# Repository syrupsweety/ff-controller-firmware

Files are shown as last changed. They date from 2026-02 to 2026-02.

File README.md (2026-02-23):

# Force feedback manipulator firmware

This is a custom force feedback controller firmware for the RP2350 microcontroller with ROS2 integration.

## Hardware features

- Microcontroller: RP2350

- Input sensors:

  - Piezo sensor (12-bit ADC) for force/vibration detection
  - Analog joystick (X/Y axes, 12-bit ADC)
  - 3 digital buttons (active-low with pull-ups)

- Actuator interface: UART (9600 baud) for motor control

- Communication: I2C slave interface (400kHz Fast Mode, address 0x08)

## Software Architecture

- Firmware: Bare-metal C using Pico SDK

  - ADC reader with moving average filtering
  - I2C slave with IRQ-based TX/RX handling
  - UART motor command protocol (framed packets)

- ROS2 driver: C++ node running on host machine

  - Polls controller via I2C at configurable rate (default 50Hz)
  - Publishes sensor data to `/controller/input` topic
  - Subscribes to `/controller/motor_command` for actuator commands

## Protocol

- I2C Read: 8 bytes (controller data + XOR checksum)
- I2C Write: 4 bytes [START, speed, dir+enable, END]

## Build

- Firmware compiles to .uf2 for drag-and-drop flashing
- ROS2 packages build with colcon
- Automated build/flash scripts included

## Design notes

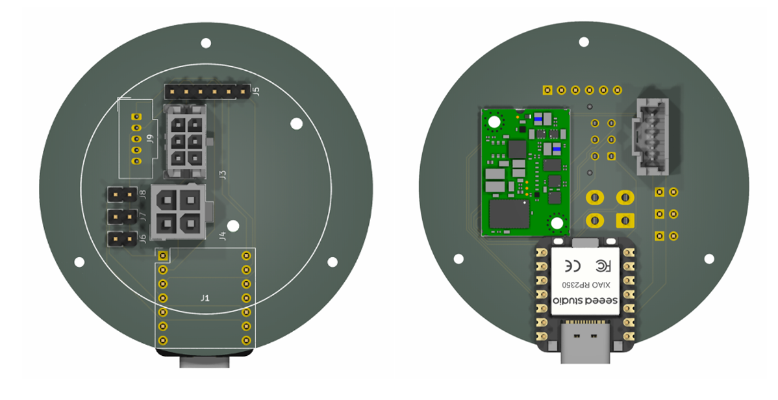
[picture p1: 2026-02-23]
schematics/screenshots/render.png

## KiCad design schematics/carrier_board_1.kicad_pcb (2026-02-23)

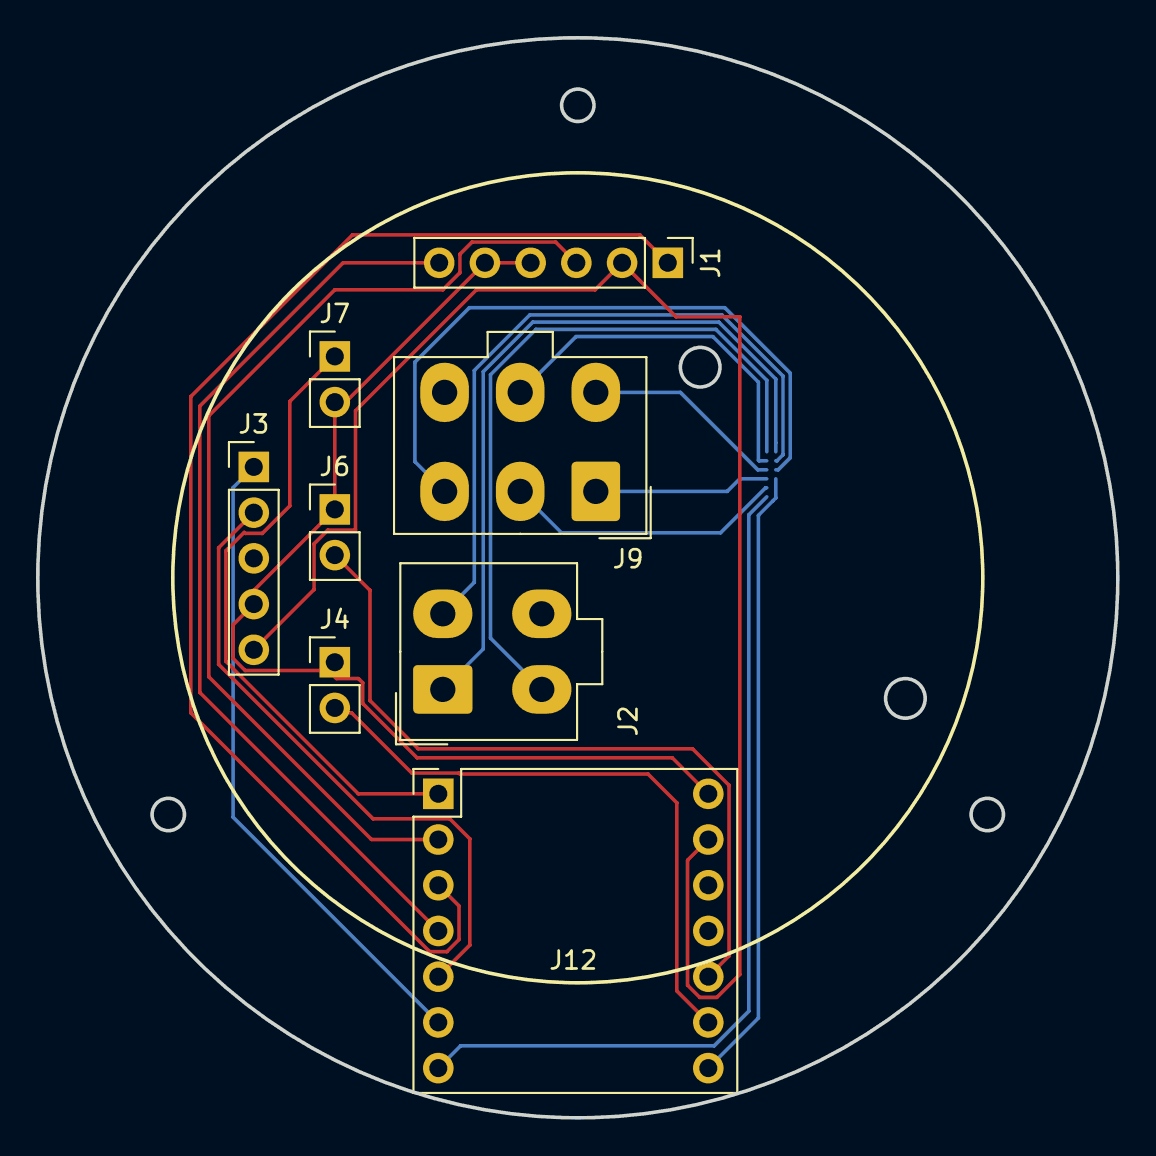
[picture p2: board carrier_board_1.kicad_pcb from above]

Board: 2 copper layers, 60.0 x 60.0 mm, 8 parts (0 on the bottom side), 10 nets.

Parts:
J1: joystick; PinHeader_1x06_P2.54mm_Vertical
J2: 4 pin BLDC; Molex_Mini-Fit_Jr_5566-04A_2x02_P4.20mm_Vertical
J3: econ; PinHeader_1x05_P2.54mm_Vertical
J4: button1; PinHeader_1x02_P2.54mm_Vertical
J6: button0; PinHeader_1x02_P2.54mm_Vertical
J7: piezo; PinHeader_1x02_P2.54mm_Vertical
J9: 6 pin BLDC; Molex_Mini-Fit_Jr_5566-06A_2x03_P4.20mm_Vertical
J12: XIAO RP2350; PinHeader_2x07_P2.54mm_Vertical

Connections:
unnamed: J1.LR (1), J12.A2 (5)
unnamed: J1.GND (2), J3.GND (4), J12.GND (4)
unnamed: J1.UD (3), J12.A1 (3)
unnamed: J1.B0 (5), J1.VCC (4), J3.5v (5), J4.1, J6.1, J7.2, J12.5V (2)
unnamed: J1.B1 (6), J12.D3 (7)
unnamed: J7.1, J12.A0 (1)
unnamed: J3.SDA (2), J12.SDA1 (9)
unnamed: J6.2, J12.D9 (10)
unnamed: J3.SCL (1), J12.SCL1 (11)
unnamed: J4.2, J12.D8 (12)

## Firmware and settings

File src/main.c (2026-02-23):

#include "pico/stdlib.h"
#include "hardware/adc.h"
#include "config.h"
#include "controller.h"
#include "i2c_slave.h"
#include "adc_reader.h"
#include "uart_motor.h"

int main(void) {
    // Standard Pico SDK initialization
    stdio_init_all();
    
    // Initialize hardware subsystems
    adc_init();
    adc_reader_init();
    controller_gpio_init();
    uart_motor_init();
    i2c_slave_init();
    
    printf("RP2350 Controller initialized @ 0x%02X\n", CONTROLLER_I2C_ADDRESS);
    
    controller_input_t input = {0};
    motor_command_t command = {0};
    
    while (true) {
        controller_read_inputs(&input);
        
        i2c_slave_prepare_response(&input);
        
        if (i2c_slave_get_command(&command)) {
            controller_process_command(&command);
        }
        
        sleep_us(1000);
    }
}

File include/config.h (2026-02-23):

#pragma once

#include "pico/stdlib.h"
#include "hardware/adc.h"
#include "hardware/i2c.h"
#include "hardware/uart.h"

// ===== I2C Configuration =====
#define CONTROLLER_I2C_PORT         i2c0
#define CONTROLLER_I2C_SDA_PIN      4
#define CONTROLLER_I2C_SCL_PIN      5
#define CONTROLLER_I2C_ADDRESS      0x08
#define CONTROLLER_I2C_BAUDRATE     400000  // 400 kHz Fast Mode

// ===== GPIO Pin Assignments =====
#define BTN_0_PIN                   9
#define BTN_1_PIN                   8
#define BTN_JOY_PIN                 3
#define PIEZO_ADC_PIN               0  // ADC0 -> GPIO26
#define JOY_X_ADC_PIN               2  // ADC2 -> GPIO28
#define JOY_Y_ADC_PIN               1  // ADC1 -> GPIO27

// ===== UART Motor Interface =====
#define MOTOR_UART_PORT             uart1
#define MOTOR_UART_TX_PIN           12
#define MOTOR_UART_RX_PIN           13
#define MOTOR_UART_BAUDRATE         9600
#define MOTOR_UART_ID               1

// ===== ADC Configuration =====
#define ADC_RESOLUTION_BITS         12
#define ADC_MAX_VALUE               ((1 << ADC_RESOLUTION_BITS) - 1)
#define ADC_SAMPLE_INTERVAL_US      1000

// ===== I2C Protocol Definition =====
#define I2C_RX_BUFFER_SIZE          16
#define I2C_TX_BUFFER_SIZE          16
#define PROTOCOL_START_BYTE         0xAA
#define PROTOCOL_END_BYTE           0x55
#define PROTOCOL_HEADER_SIZE        2
#define PROTOCOL_PAYLOAD_SIZE       3
#define PROTOCOL_FOOTER_SIZE        1
#define PROTOCOL_TOTAL_SIZE         (PROTOCOL_HEADER_SIZE + PROTOCOL_PAYLOAD_SIZE + PROTOCOL_FOOTER_SIZE)

// ===== Data Structures =====
typedef struct __attribute__((packed)) {
    uint8_t speed;      // 0-255
    uint8_t direction;  // 0=CCW, 1=CW
    uint8_t enable;     // 0=disable, 1=enable
} motor_command_t;

typedef struct __attribute__((packed)) {
    uint8_t buttons;            // Bitmask: bit0=BTN0, bit1=BTN1, bit2=JOY_BTN
    uint8_t reserved;           // Padding for alignment
    uint16_t piezo_value;       // 0-4095
    uint16_t joystick_x;        // 0-4095
    uint16_t joystick_y;        // 0-4095
    uint8_t checksum;           // Simple XOR checksum
} controller_input_t;

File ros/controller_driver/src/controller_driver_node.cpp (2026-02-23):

#include "rclcpp/rclcpp.hpp"
#include "controller_msgs/msg/controller_input.hpp"
#include "controller_msgs/msg/motor_command.hpp"
#include <linux/i2c-dev.h>
#include <sys/ioctl.h>
#include <fcntl.h>
#include <unistd.h>
#include <cstring>

class ControllerDriver : public rclcpp::Node {
public:
    ControllerDriver() 
    : Node("controller_driver"),
      i2c_fd_(-1),
      i2c_address_(0x08)
    {
        // Declare parameters
        this->declare_parameter<std::string>("i2c_device", "/dev/i2c-1");
        this->declare_parameter<int>("i2c_address", 0x08);
        this->declare_parameter<int>("publish_rate_hz", 50);
        
        // Initialize I2C
        init_i2c();
        
        // Create publishers/subscribers
        input_pub_ = this->create_publisher<controller_msgs::msg::ControllerInput>(
            "controller/input", 10);
        command_sub_ = this->create_subscription<controller_msgs::msg::MotorCommand>(
            "controller/motor_command", 10,
            [this](const controller_msgs::msg::MotorCommand::SharedPtr msg) {
                send_motor_command(msg);
            });
        
        // Timer for periodic input polling
        auto period = std::chrono::milliseconds(
            1000 / this->get_parameter("publish_rate_hz").as_int());
        timer_ = this->create_wall_timer(period, 
            std::bind(&ControllerDriver::poll_controller, this));
        
        RCLCPP_INFO(this->get_logger(), "Controller driver initialized");
    }

private:
    void init_i2c() {
        std::string device = this->get_parameter("i2c_device").as_string();
        i2c_address_ = static_cast<uint8_t>(
            this->get_parameter("i2c_address").as_int());
        
        i2c_fd_ = open(device.c_str(), O_RDWR);
        if (i2c_fd_ < 0) {
            RCLCPP_ERROR(this->get_logger(), "Failed to open I2C device: %s", device.c_str());
            return;
        }
        
        if (ioctl(i2c_fd_, I2C_SLAVE, i2c_address_) < 0) {
            RCLCPP_ERROR(this->get_logger(), "Failed to acquire I2C bus access");
            close(i2c_fd_);
            i2c_fd_ = -1;
            return;
        }
        
        RCLCPP_INFO(this->get_logger(), "I2C connected to 0x%02X on %s", 
                   i2c_address_, device.c_str());
    }
    
    void poll_controller() {
        if (i2c_fd_ < 0) return;
        
        controller_msgs::msg::ControllerInput msg;
        msg.stamp = this->now();
        
        // Request data from RP2350
        uint8_t buffer[8];
        if (read(i2c_fd_, buffer, sizeof(buffer)) == sizeof(buffer)) {
            // Validate checksum (XOR of first 7 bytes)
            uint8_t checksum = 0;
            for (int i = 0; i < 7; i++) checksum ^= buffer[i];
            
            if (checksum == buffer[7]) {
                msg.buttons = buffer[0];  // buttons is 1st byte
                msg.piezo_value = (buffer[2] << 8) | buffer[3];
                msg.joystick_x = (buffer[4] << 8) | buffer[5];
                msg.joystick_y = (buffer[6] << 8) | buffer[7];
                
                msg.joystick_x_norm = (static_cast<float>(msg.joystick_x) / 4095.0f) * 2.0f - 1.0f;
                msg.joystick_y_norm = (static_cast<float>(msg.joystick_y) / 4095.0f) * 2.0f - 1.0f;
                msg.piezo_normalized = static_cast<float>(msg.piezo_value) / 4095.0f;
                
                input_pub_->publish(msg);
            } else {
                RCLCPP_WARN_THROTTLE(this->get_logger(), 
                    *this->get_clock(), 5000, "I2C checksum mismatch");
            }
        }
    }
    
    void send_motor_command(const controller_msgs::msg::MotorCommand::SharedPtr cmd) {
        if (i2c_fd_ < 0) return;
        
        uint8_t buffer[5] = {
            0xAA,
            cmd->speed,
            static_cast<uint8_t>(cmd->direction | (cmd->enable ? 0x02 : 0x00)),
            0x55
        };
        
        if (write(i2c_fd_, buffer, sizeof(buffer)) != sizeof(buffer)) {
            RCLCPP_WARN(this->get_logger(), "Failed to send motor command");
        }
    }
    
    // Member variables
    rclcpp::Publisher<controller_msgs::msg::ControllerInput>::SharedPtr input_pub_;
    rclcpp::Subscription<controller_msgs::msg::MotorCommand>::SharedPtr command_sub_;
    rclcpp::TimerBase::SharedPtr timer_;
    
    int i2c_fd_;
    uint8_t i2c_address_;
};

int main(int argc, char * argv[]) {
    rclcpp::init(argc, argv);
    rclcpp::spin(std::make_shared<ControllerDriver>());
    rclcpp::shutdown();
    return 0;
}

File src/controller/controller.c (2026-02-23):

#include "controller.h"
#include "config.h"
#include "adc_reader.h"
#include "uart_motor.h"
#include "hardware/gpio.h"

void controller_gpio_init(void) {
    // Button pins with pull-up
    const uint8_t btn_pins[] = {BTN_0_PIN, BTN_1_PIN, BTN_JOY_PIN};
    for (size_t i = 0; i < sizeof(btn_pins)/sizeof(btn_pins[0]); i++) {
        gpio_init(btn_pins[i]);
        gpio_set_dir(btn_pins[i], GPIO_IN);
        gpio_pull_up(btn_pins[i]);
    }
    
    // ADC pins
    adc_gpio_init(26 + PIEZO_ADC_PIN);   // GPIO26 = ADC0
    adc_gpio_init(26 + JOY_Y_ADC_PIN);   // GPIO27 = ADC1  
    adc_gpio_init(26 + JOY_X_ADC_PIN);   // GPIO28 = ADC2
}

void controller_read_inputs(controller_input_t *input) {
    // Read digital buttons (active-low with pullup)
    input->buttons = 0;
    if (!gpio_get(BTN_0_PIN)) input->buttons |= (1 << 0);
    if (!gpio_get(BTN_1_PIN)) input->buttons |= (1 << 1);
    if (!gpio_get(BTN_JOY_PIN)) input->buttons |= (1 << 2);
    
    // Read analog sensors
    input->piezo_value = adc_reader_read(PIEZO_ADC_PIN);
    input->joystick_x = adc_reader_read(JOY_X_ADC_PIN);
    input->joystick_y = adc_reader_read(JOY_Y_ADC_PIN);
}

void controller_process_command(const motor_command_t *cmd) {
    uart_motor_send_command(cmd);
}
